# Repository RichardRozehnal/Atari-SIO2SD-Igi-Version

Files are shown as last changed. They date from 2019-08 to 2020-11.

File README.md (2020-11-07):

# Atari SIO2SD Igi Version

SIO2SD je zařízení, které vám umožní nahrávat programy a hry do Atari přes SIO konektor z SD/MMC karty.

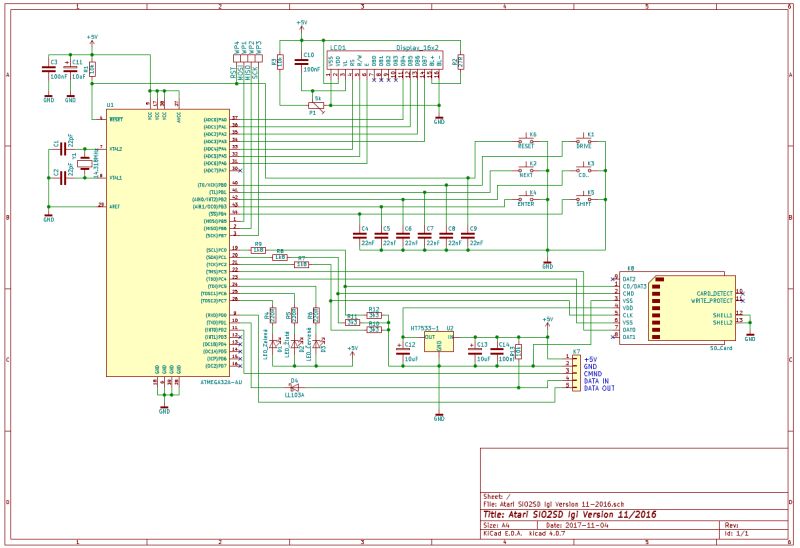
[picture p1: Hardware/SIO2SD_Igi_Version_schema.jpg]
Atari SIO2SD Igi Version schema SIO2SD Igi Version schema


## Seznam součástek:

| Ref | Qnty | Value | Cmp name |
|---|:----:|---|---|
| C1, C2, | 2 | 22pF | C_1206 |
| C9, C8, C7, C6, C5, C4,  | 6 | 22nF | C_1206 |
| C11, C13, C12, | 3 | 10uF | C_Tantal_A/3216 |
| C14, C3, C10, | 3 | 100nF | C_1206 |
| D1, | 1 | LED_Zelená | LED_5mm_Zelená |
| D2, | 1 | LED_Žlutá | LED_5mm_Žlutá |
| D3, | 1 | LED_Červená | LED_5mm_Červená |
| D4, | 1 | LL103A | LL103A |
| K1, | 1 | DRIVE | Mikrospínač_6x6x5mm |
| K2, | 1 | NEXT | Mikrospínač_6x6x5mm |
| K3, | 1 | CD.. | Mikrospínač_6x6x5mm |
| K4, | 1 | ENTER | Mikrospínač_6x6x5mm |
| K5, | 1 | SHIFT | Mikrospínač_6x6x5mm |
| K6, | 1 | RESET | Mikrospínač_6x6x5mm |
| K7, | 1 | KF2510-5_Angled_Pitch2.54mm | KF2510-5_Angled_Pitch2.54mm |
| K8, | 1 | SD_Card | SD_Card |
| LCD1, | 1 | Display_16x2 | Display_16x2 |
| P1, | 1 | 5k | 3362P |
| R1, R3, R13, | 3 | 10k | R_1206 |
| R2, | 1 | 27R | R_1206 |
| R4, R6, R5, | 3 | 220R | R_1206 |
| R9, R8, R7, | 3 | 1k8 | R_1206 |
| R11, R12, R10, | 3 | 3k3 | R_1206 |
| U1, | 1 | ATMEGA32A-AU | ATMEGA32A-AU |
| U2, | 1 | HT7533-1 | HT7533-1 |
| WP1, | 1 | MOSI | Wire_Pad |
| WP2, | 1 | MISO | Wire_Pad |
| WP3, | 1 | SCK | Wire_Pad |
| WP4, | 1 | RST | Wire_Pad |
| Y1, | 1 | 14.318MHz | Krystal_HC49-U_Vertical |

## Fotky hotového výrobku (DPS verze 1):

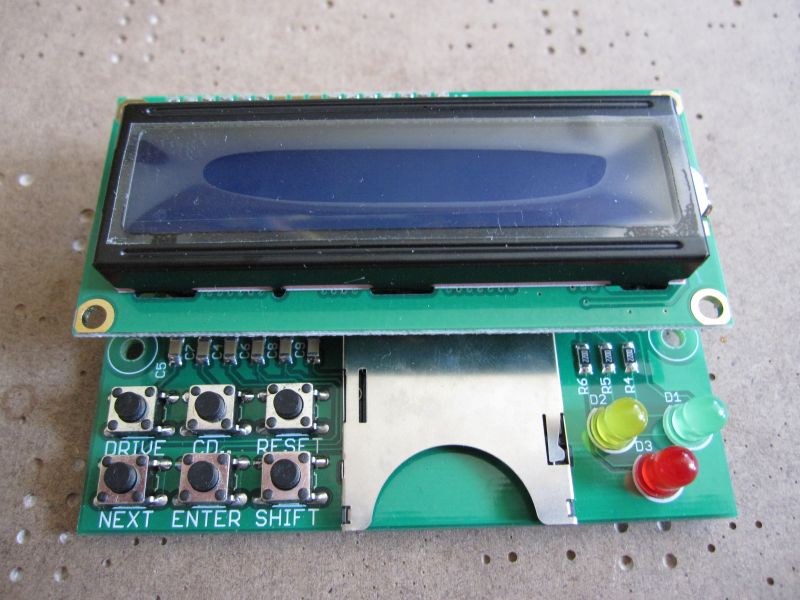
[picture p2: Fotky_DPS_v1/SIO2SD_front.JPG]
Atari SIO2SD front

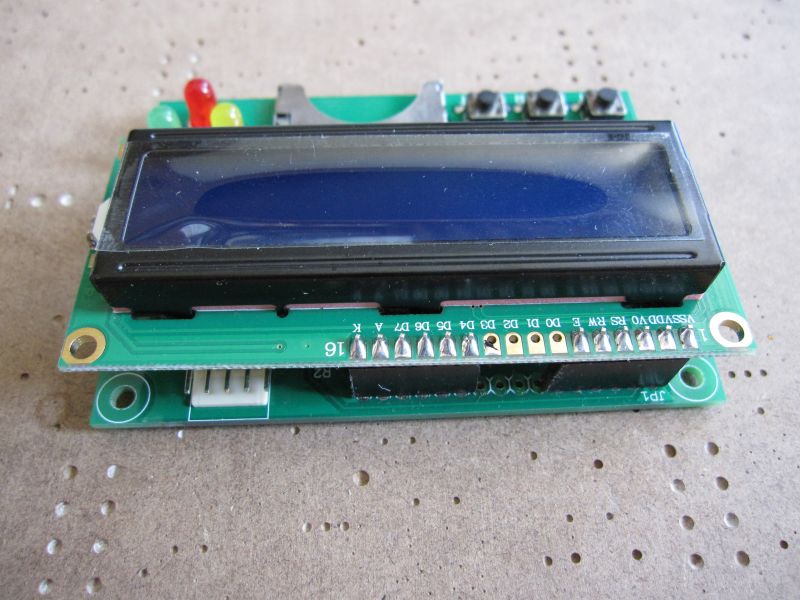
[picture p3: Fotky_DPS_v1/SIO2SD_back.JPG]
Atari SIO2SD back

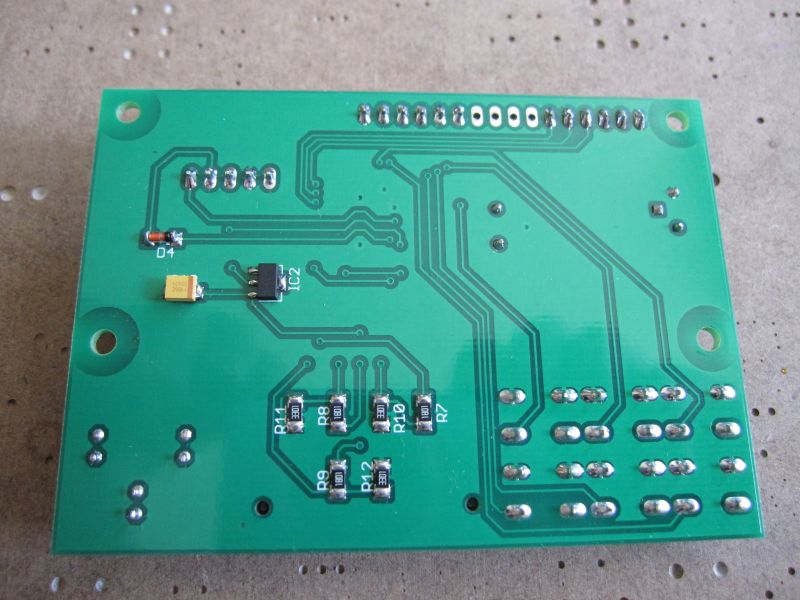
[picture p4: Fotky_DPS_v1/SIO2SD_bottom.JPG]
Atari SIO2SD bottom

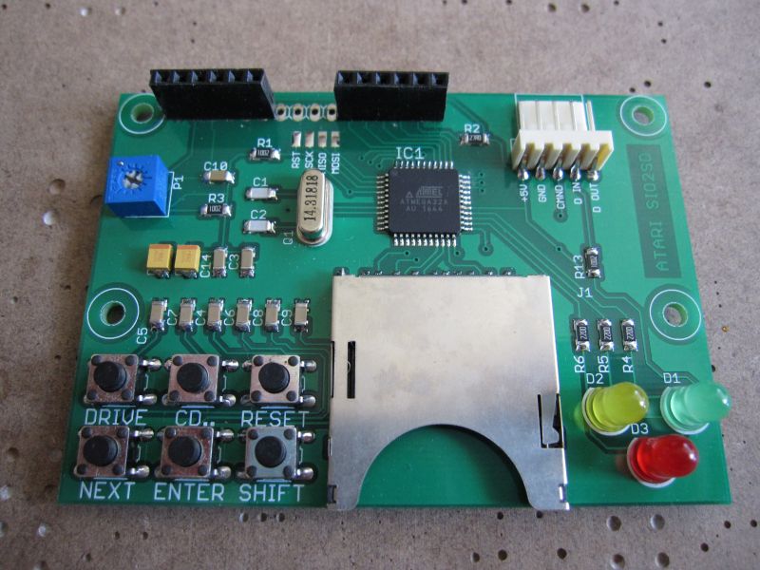
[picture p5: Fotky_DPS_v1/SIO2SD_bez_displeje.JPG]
Atari SIO2SD bez displeje

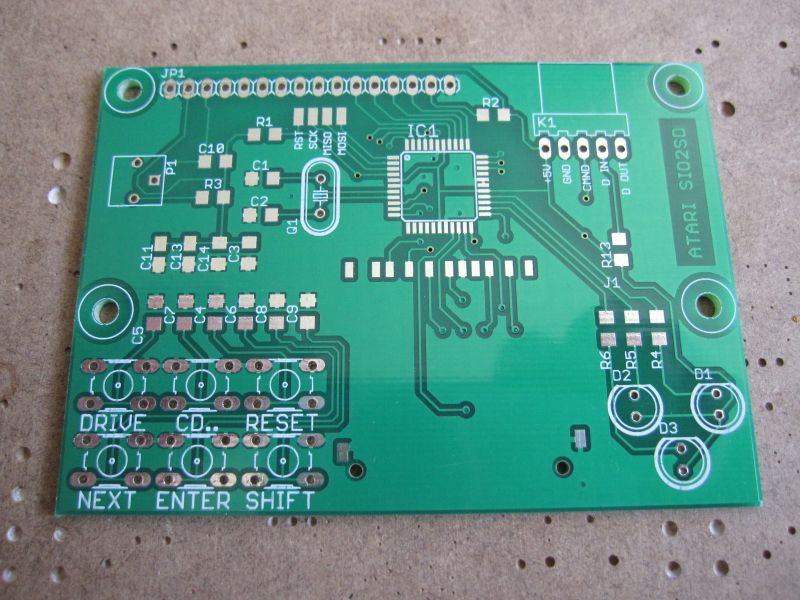
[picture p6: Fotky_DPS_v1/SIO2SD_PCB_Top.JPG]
Atari SIO2SD PCB Top

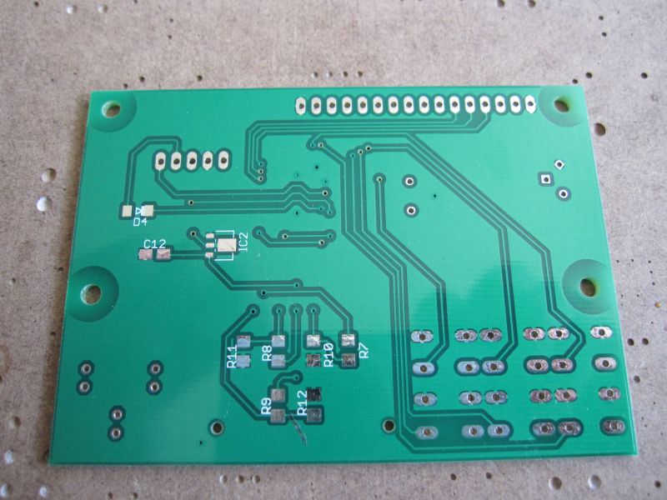
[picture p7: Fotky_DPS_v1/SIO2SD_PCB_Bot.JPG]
Atari SIO2SD PCB Bot


## Původní autoři zařízení jsou:

Device inventor and AVR software developer: Jakub Kruszona-Zawadzki<br>
ATARI software developer and tester: Paweł Nowak (Pajero/MadTeam)<br>
NVC developer: Marcin Sochacki (Montezuma)<br>
Tester (also new SMD PCB designer - still not finished): Jakub Husak<br>

Tato verze má vylepšené a zjednodušené zapojení od [Igiho](http://blog.3b2.sk/igi/post/SIO2SD-3verzia.aspx).
Otestováno na Atari 800XE a vše funguje bez problému.

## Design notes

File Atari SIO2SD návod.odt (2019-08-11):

Atari SIO2SD návod

### Příprava karty

Kartu MMC/SDSC/SDHC (měla by fungovat i SDXC) naformátujte na FAT32. Vytvořte na ni adresář ATARI. Soubor Sio2SD v35.xex z archivu Configurator_35.zip přejmenujte na Sio2SD.xex a přehrejte ho do rootu karty. Do adresáře ATARI přehrejte soubor Sio2SD_CFG_PJ.HLP. V adresáři ATARI můžete vytvářet další adresáře např.: HRY, DEMA, apod. a do těchto již nahrát konkrétní soubory ATR, XEX, COM, XFD. Doporučuje se nahrát maximálně okolo 100 souborů do jednoho adresáře. Protože zařízení SIO2SD nezobrazuje soubory na kartě podle abecedy, ale podle fyzického umístění na kartě, je potřeba (pokud budete chtít) soubory seřadit abecedně pomocí programu DriveSort.

### Příprava kabelu SIO2SD → Atari SIO

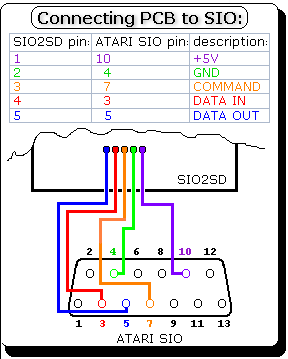
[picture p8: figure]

### Rozložení tlačítek

K1 (DRIVE) | K3 (CD..) | RESET
K2 (NEXT) | K4 (ENTER) | SHIFT

### Ovládání

K1: next atari drive (D1,D2,..)

SHIFT+K1: previous atari drive (D1,D2,..)

K2: next file/folder

SHIFT+K2: previous file/folder

K3: parent directory (cd ..)

SHIFT+K3: swap D1 and D2 (up to version 2.2 - firmware upgrade)

K4: go to folder/map file to current atari drive

SHIFT+K4: turn off current atari drive ("eject disk")

RESET: vyresetuje SIO2SD zařízení

Dvojitým stisknutím tlačítka SHIFT se dostanete do Setup módu. V tomto módu mají tlačítka následující funkce:

K1: next option

SHIFT+K1: previous option

K2: next option setting

SHIFT+K2: previous option setting

K3: back to normal mode

SHIFT+K3: firmware upgrade

### Možnosti nastavení v Setup módu

sio high speed

off

hsindex from 1 to 16 (6 is the default setting)

cfg tool load (when to override D1 to load configuration program)

never

startup+shift - only when SHIFT was pressed during startup (power on)

every startup

D1 is off - When D1 is not assigned

shift pressed - SHIFT always cause D1 override (tested on every SIO 'S' command on D1 - available from version 2.2)

LED mode (meanig of LEDs)

SD read/write - first LED shows SD reads, second LED shows SD writes

SIO read/write - first LED shows SIO reads, second SIO writes

SD act/SIO act - first LED shows any SD activity, second any SIO activity

device id (number of device for SIO2SD.XEX - available from version 2.2)

values from 0 to 3

write protect (write protection in ATR files - available from version 2.2)

never - ATR's are always R/W (write protect flag ignored)

obey ATR flag - obey ATR write protect flag - default

always - ATR's are always R/O

disks to roll (How many disks will be rolled on SHIFT+K3)

values from 2 (swap D1 and D2) to 15 (shift all disks)

key rep delay (keyboard autorepetition delay - in 1/50s.)

values from 0 to 50 (0 - 1s)

key rep step (keyboard autorepetition step - in 1/50s.)

values from 0 to 10 (0 – 0.2s)

### Ovládání v Configurator 3.5

Stiskněte a držte SHIFT na SIO2SD zařízení a zapněte Atari. Nahraje se Configurator ve kterém se zobrazí soubory na kartě, které můžete spouštět.

Spuštění souboru (hry): označte soubor (hru), kterou chcete spustit, stiskněte a držte OPTION na Atari (kvůli vypnutí Atari basicu) a stiskněte na 1-2s klávesu RETURN. OPTION pusťte až se hra začne nahrávat.

Přiřazení souboru k disketovce (D1, D2, atd.): označte požadovaný soubor a stiskněte na Atari klávesnici číslo požadované disketovky.

Odebrání souboru z disketovky (D1, D2, atd.): stiskněte na Atari klávesnici SHIFT + číslo požadované disketovky.

CTRL+T: přepíná mezi L (reálné disketovky), M (mapping), V (virtuální disketovky)

CAPS on/off: zapíná/vypíná skrolování názvů souborů při načítání adresáře

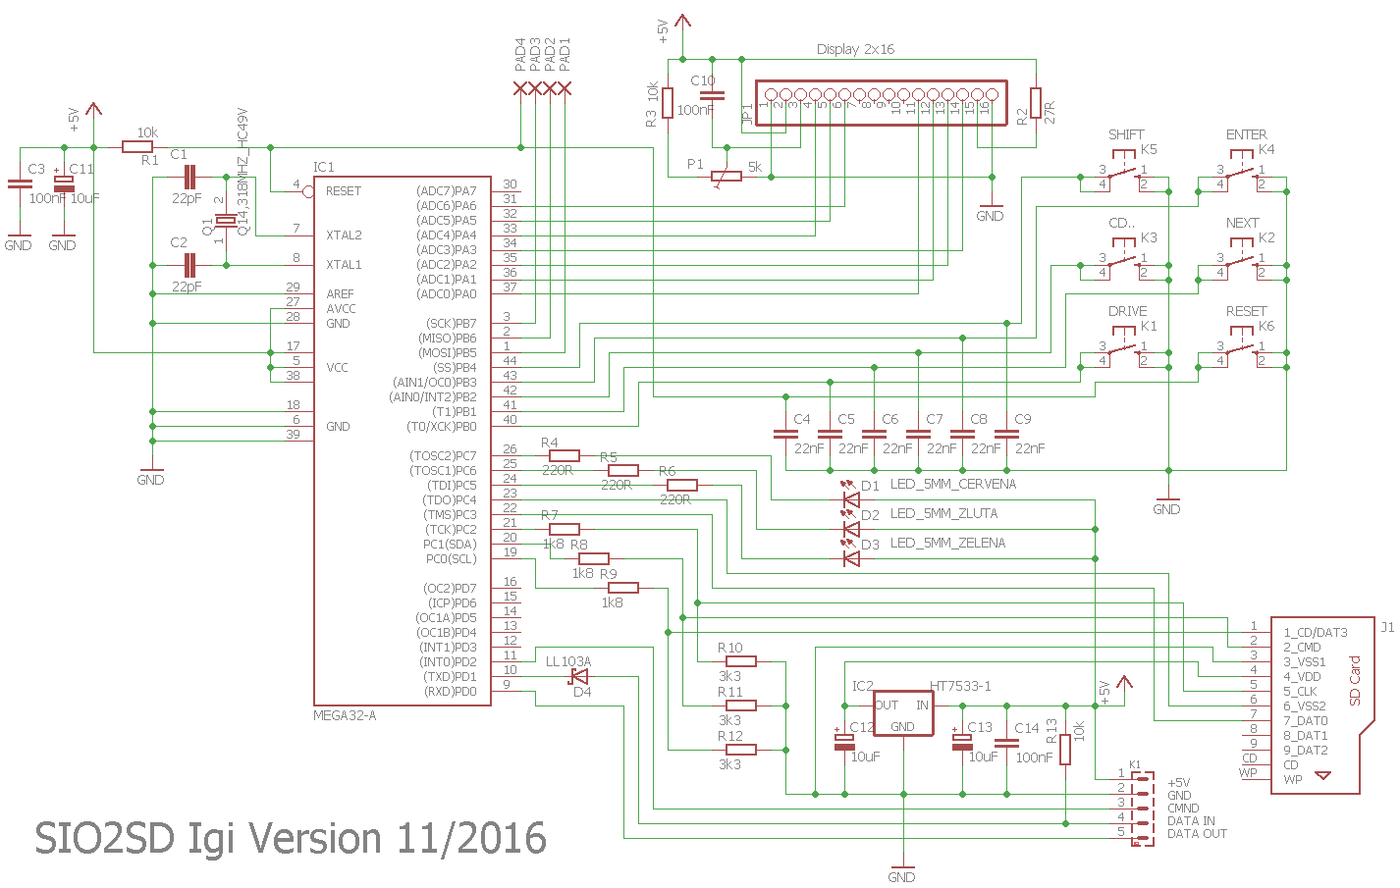
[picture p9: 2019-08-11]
Hardware/1. verze_DPS_v_Eagle/Schema.png

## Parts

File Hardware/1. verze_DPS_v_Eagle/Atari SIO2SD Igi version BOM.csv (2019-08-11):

Qty | Value | Device | Package | Parts | Description
1 |  | 693063010911 | 693063010911 | J1 | WR-CRD SD CARD CONNECTOR PUSH & PULL WITH CARD DETECTION 9PINS=>Code : Con_I-O_COM_CRD_SD_Normal_693063010911
1 |  | PSH02-05W | PSH02-05W | K1 | Konektory se zamkem - vidlice - 5pin
4 |  | SMD2 | SMD1,27-2,54 | PAD1, PAD2, PAD3, PAD4 | SMD PAD
3 | 100nF | C-SMD1206 | 1206 | C3, C10, C14 | Kondenzátory keramické SMD 50 V
3 | 10k | R1206 | R1206 | R1, R3, R13 | Rezistor SMD 1206
3 | 10uF | CTSA | A/3216 | C11, C12, C13 | Kondenzátory tantalové - SMD
3 | 1k8 | R1206 | R1206 | R7, R8, R9 | Rezistor SMD 1206
3 | 220R | R1206 | R1206 | R4, R5, R6 | Rezistor SMD 1206
6 | 22nF | C-SMD1206 | 1206 | C4, C5, C6, C7, C8, C9 | Kondenzátory keramické SMD 50 V
2 | 22pF | C-SMD1206 | 1206 | C1, C2 | Kondenzátory keramické SMD 50 V
1 | 27R | R1206 | R1206 | R2 | Rezistor SMD 1206
3 | 3k3 | R1206 | R1206 | R10, R11, R12 | Rezistor SMD 1206
1 | 5k | 3362P | 3362P | P1 | Odporové trimry 3362P
1 | BAT54S | BAT54S | SOT23 | D4 | Schottky
1 | Display 2x16 | PINHD-1X16 | 1X16 | JP1 | PIN HEADER
1 | HT7533-1 | HT7533-1_SMD | SOT89R | IC2 | VOLTAGE REGULATOR
1 | K1 | 10-XX | B3F-10XX | DRIVE | OMRON SWITCH
1 | K2 | 10-XX | B3F-10XX | NEXT | OMRON SWITCH
1 | K3 | 10-XX | B3F-10XX | CD.. | OMRON SWITCH
1 | K4 | 10-XX | B3F-10XX | ENTER | OMRON SWITCH
1 | K5 | 10-XX | B3F-10XX | SHIFT | OMRON SWITCH
1 | K6 | 10-XX | B3F-10XX | RESET | OMRON SWITCH
1 | LED_5MM_CERVENA | LED_5MM_CERVENA | A5,0 | D1 | LED 5mm
1 | LED_5MM_ZELENA | LED_5MM_ZELENA | A5,0 | D3 | LED 5mm
1 | LED_5MM_ZLUTA | LED_5MM_ZLUTA | A5,0 | D2 | LED 5mm
1 | MEGA32-A | MEGA32-A | TQFP44 | IC1 | MICROCONTROLLER
1 | Q14,318MHZ_HC49V | Q14,318MHZ_HC49V | HC49U-V | Q1 | Krystal s pouzdrem HC-49U

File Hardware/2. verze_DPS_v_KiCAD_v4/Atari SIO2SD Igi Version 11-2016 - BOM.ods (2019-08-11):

Source: | C:/Program Files/KiCad/Projects/Atari SIO2SD Igi Version 11-2016.sch
Date: | 26/11/2017 12:40:37
Tool: | Eeschema 4.0.7
Generator: | KiCad/bin/scripting/plugins/bom_csv_grouped_by_value_with_fp.py
Component Count: | 48
Ref | Qnty | Value | Cmp name
C1, C2, | 2 | 22pF | C_1206
C9, C8, C7, C6, C5, C4, | 6 | 22nF | C_1206
C11, C13, C12, | 3 | 10uF | C_Tantal_A/3216
C14, C3, C10, | 3 | 100nF | C_1206
D1, | 1 | LED_ZelenĂˇ | LED_5mm_ZelenĂˇ
D2, | 1 | LED_Ĺ˝lutĂˇ | LED_5mm_Ĺ˝lutĂˇ
D3, | 1 | LED_ÄŚervenĂˇ | LED_5mm_ÄŚervenĂˇ
D4, | 1 | LL103A | LL103A
K1, | 1 | DRIVE | MikrospĂnaÄŤ_6x6x5mm
K2, | 1 | NEXT | MikrospĂnaÄŤ_6x6x5mm
K3, | 1 | CD.. | MikrospĂnaÄŤ_6x6x5mm
K4, | 1 | ENTER | MikrospĂnaÄŤ_6x6x5mm
K5, | 1 | SHIFT | MikrospĂnaÄŤ_6x6x5mm
K6, | 1 | RESET | MikrospĂnaÄŤ_6x6x5mm
K7, | 1 | KF2510-5_Angled_Pitch2.54mm | KF2510-5_Angled_Pitch2.54mm
K8, | 1 | SD_Card | SD_Card
LCD1, | 1 | Display_16x2 | Display_16x2
P1, | 1 | 5k | 3362P
R1, R3, R13, | 3 | 10k | R_1206
R2, | 1 | 27R | R_1206
R4, R6, R5, | 3 | 220R | R_1206
R9, R8, R7, | 3 | 1k8 | R_1206
R11, R12, R10, | 3 | 3k3 | R_1206
U1, | 1 | ATMEGA32A-AU | ATMEGA32A-AU
U2, | 1 | HT7533-1 | HT7533-1
WP1, | 1 | MOSI | Wire_Pad
WP2, | 1 | MISO | Wire_Pad
WP3, | 1 | SCK | Wire_Pad
WP4, | 1 | RST | Wire_Pad
Y1, | 1 | 14.318MHz | Krystal_HC49-U_Vertical

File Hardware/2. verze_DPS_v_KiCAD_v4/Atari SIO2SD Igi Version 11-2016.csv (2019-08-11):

Source: | C:/Program Files/KiCad/Projects/Atari SIO2SD Igi Version 11-2016.sch
Date: | 26/11/2017 12:40:37
Tool: | Eeschema 4.0.7
Generator: | C:/Program Files/KiCad/bin/scripting/plugins/bom_csv_grouped_by_value_with_fp.py
Component Count: | 48
Ref | Qnty | Value | Cmp name | Footprint | Description | Vendor
C1, C2, | 2 | 22pF | C_1206 | Kondenzátory_SMD:C_1206 | Nepolarizovaný kondenzátor 1206
C9, C8, C7, C6, C5, C4, | 6 | 22nF | C_1206 | Kondenzátory_SMD:C_1206 | Nepolarizovaný kondenzátor 1206
C11, C13, C12, | 3 | 10uF | C_Tantal_A/3216 | Kondenzátory_tantalové_SMD:CP_Tantalum_Case-A_EIA-3216-18_Reflow | Kondenzátor tantalový A/3216
C14, C3, C10, | 3 | 100nF | C_1206 | Kondenzátory_SMD:C_1206 | Nepolarizovaný kondenzátor 1206
D1, | 1 | LED_Zelená | LED_5mm_Zelená | Diody_LED_THT:LED_D5.0mm | LED 5mm Zelená
D2, | 1 | LED_Žlutá | LED_5mm_Žlutá | Diody_LED_THT:LED_D5.0mm | LED 5mm Žlutá
D3, | 1 | LED_Červená | LED_5mm_Červená | Diody_LED_THT:LED_D5.0mm | LED 5mm Červená
D4, | 1 | LL103A | LL103A | Diody_Schottky_SMD:D_MiniMELF | Urrm = 40V, If = 0,2A, Ufm = 0,37V, Ifsm = 15A
K1, | 1 | DRIVE | Mikrospínač_6x6x5mm | Vypínače, přepínače, tlačítka_THT:SW_PUSH_6mm_h5mm | Mikrospínač 6 x 6 x 5 mm, Omron
K2, | 1 | NEXT | Mikrospínač_6x6x5mm | Vypínače, přepínače, tlačítka_THT:SW_PUSH_6mm_h5mm | Mikrospínač 6 x 6 x 5 mm, Omron
K3, | 1 | CD.. | Mikrospínač_6x6x5mm | Vypínače, přepínače, tlačítka_THT:SW_PUSH_6mm_h5mm | Mikrospínač 6 x 6 x 5 mm, Omron
K4, | 1 | ENTER | Mikrospínač_6x6x5mm | Vypínače, přepínače, tlačítka_THT:SW_PUSH_6mm_h5mm | Mikrospínač 6 x 6 x 5 mm, Omron
K5, | 1 | SHIFT | Mikrospínač_6x6x5mm | Vypínače, přepínače, tlačítka_THT:SW_PUSH_6mm_h5mm | Mikrospínač 6 x 6 x 5 mm, Omron
K6, | 1 | RESET | Mikrospínač_6x6x5mm | Vypínače, přepínače, tlačítka_THT:SW_PUSH_6mm_h5mm | Mikrospínač 6 x 6 x 5 mm, Omron
K7, | 1 | KF2510-5_Angled_Pitch2.54mm | KF2510-5_Angled_Pitch2.54mm | Konektory_THT:KF2510-5_Angled_Pitch2.54mm | Konektor KF2510 (PSH02), angled, 5 pinů, 2.54mm
K8, | 1 | SD_Card | SD_Card | Konektory_SMD:SD_Card_Wurth_693061010911 | SD Card Reader
LCD1, | 1 | Display_16x2 | Display_16x2 | Displeje:LCD_16x2 | LCD 16x2
P1, | 1 | 5k | 3362P | Trimry_odporové_THT:3362P | Trimr odporový, 3362P
R1, R3, R13, | 3 | 10k | R_1206 | Rezistory_SMD:R_1206 | Rezistor 1206
R2, | 1 | 27R | R_1206 | Rezistory_SMD:R_1206 | Rezistor 1206
R4, R6, R5, | 3 | 220R | R_1206 | Rezistory_SMD:R_1206 | Rezistor 1206
R9, R8, R7, | 3 | 1k8 | R_1206 | Rezistory_SMD:R_1206 | Rezistor 1206
R11, R12, R10, | 3 | 3k3 | R_1206 | Rezistory_SMD:R_1206 | Rezistor 1206
U1, | 1 | ATMEGA32A-AU | ATMEGA32A-AU | Housings_QFP:TQFP-44_10x10mm_Pitch0.8mm | TQFP44, 32k Flash, 2k SRAM, 1k EEPROM, JTAG
U2, | 1 | HT7533-1 | HT7533-1 | Stabilizátory_SMD:SOT-89R-3 | Stabilizátor napětí 3,3V / 0,1A, max. vstupní napětí 26V, úbytek napětí 0,1V
WP1, | 1 | MOSI | Wire_Pad | Wire_Pads_SMD:Wire_Pad_1.27x2.54mm
WP2, | 1 | MISO | Wire_Pad | Wire_Pads_SMD:Wire_Pad_1.27x2.54mm
WP3, | 1 | SCK | Wire_Pad | Wire_Pads_SMD:Wire_Pad_1.27x2.54mm
WP4, | 1 | RST | Wire_Pad | Wire_Pads_SMD:Wire_Pad_1.27x2.54mm
Y1, | 1 | 14.318MHz | Krystal_HC49-U_Vertical | Krystaly_THT:Crystal_HC49-U_Vertical | Krystal, HC49-U Vertical

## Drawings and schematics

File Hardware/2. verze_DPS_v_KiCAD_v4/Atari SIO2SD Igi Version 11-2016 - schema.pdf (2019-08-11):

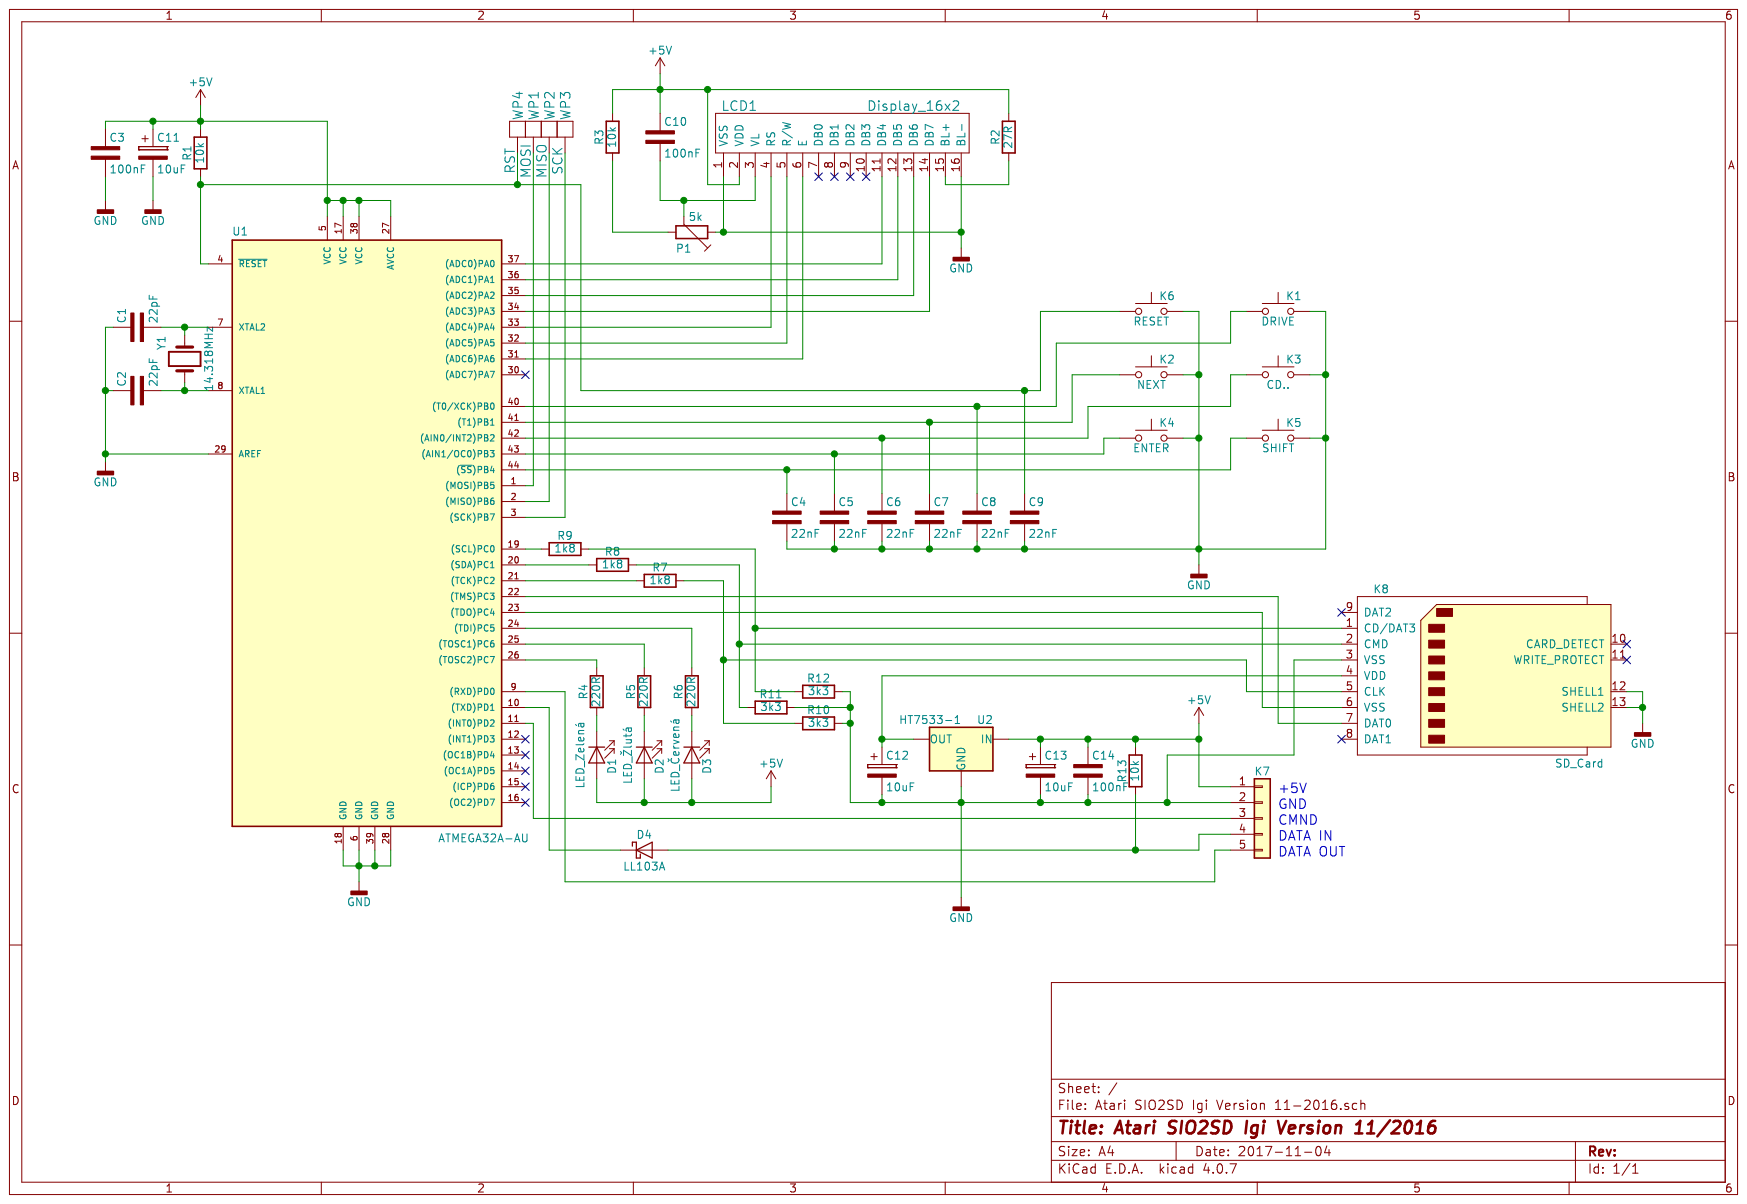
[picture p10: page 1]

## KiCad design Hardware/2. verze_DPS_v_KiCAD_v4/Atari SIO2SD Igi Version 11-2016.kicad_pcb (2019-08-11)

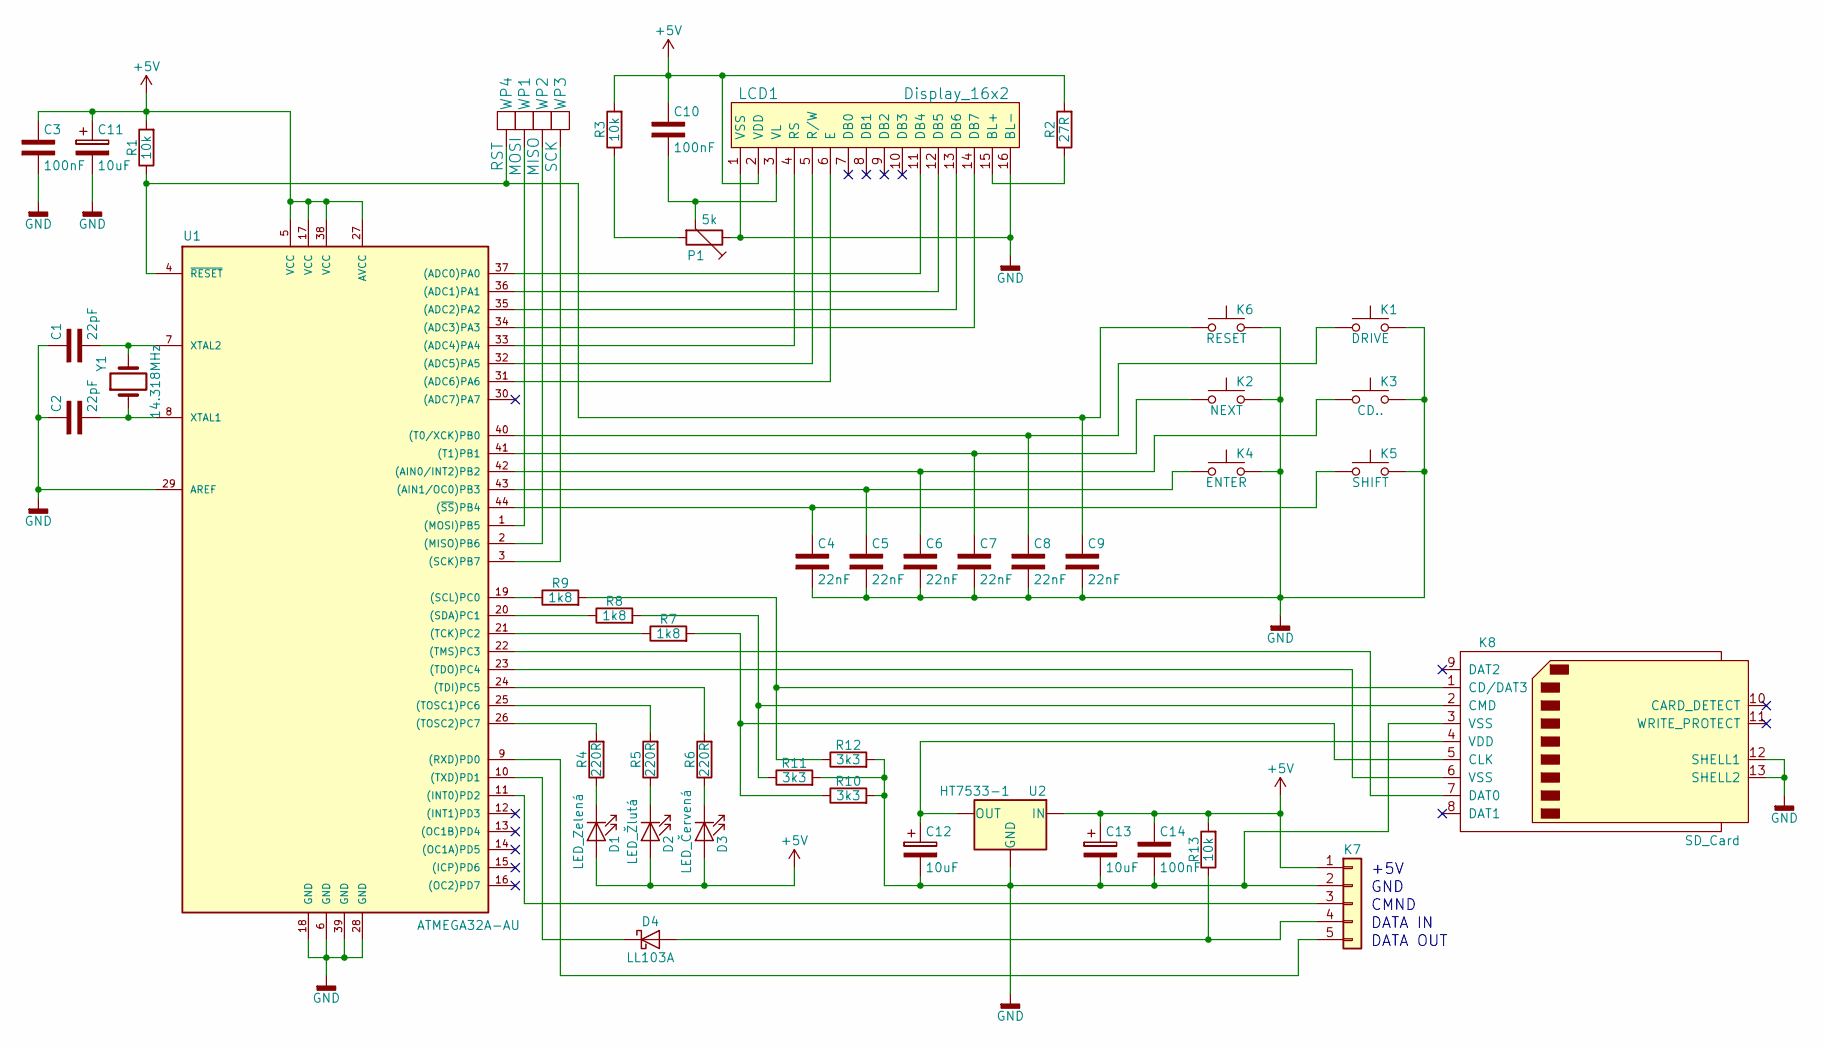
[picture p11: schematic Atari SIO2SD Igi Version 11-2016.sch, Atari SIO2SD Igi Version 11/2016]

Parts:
C1, C2: 22pF; C_1206
C3, C10, C14: 100nF; C_1206
C4, C5, C6, C7, C8, C9: 22nF; C_1206
C11, C12, C13: 10uF; CP_Tantalum_Case-A_EIA-3216-18_Reflow
D1: LED_Zelená; LED_D5.0mm
D2: LED_Žlutá; LED_D5.0mm
D3: LED_Červená; LED_D5.0mm
D4: LL103A; D_MiniMELF
K1: DRIVE; SW_PUSH_6mm_h5mm
K2: NEXT; SW_PUSH_6mm_h5mm
K3: CD..; SW_PUSH_6mm_h5mm
K4: ENTER; SW_PUSH_6mm_h5mm
K5: SHIFT; SW_PUSH_6mm_h5mm
K6: RESET; SW_PUSH_6mm_h5mm
K7: KF2510-5_Angled_Pitch2.54mm
K8: SD_Card; SD_Card_Wurth_693061010911
LCD1: Display_16x2; LCD_16x2
P1: 5k; 3362P
R1, R3, R13: 10k; R_1206
R2: 27R; R_1206
R4, R5, R6: 220R; R_1206
R7, R8, R9: 1k8; R_1206
R10, R11, R12: 3k3; R_1206
U1: ATMEGA32A-AU; TQFP-44_10x10mm_Pitch0.8mm
U2: HT7533-1; SOT-89R-3
WP1: MOSI; Wire_Pad_1.27x2.54mm
WP2: MISO; Wire_Pad_1.27x2.54mm
WP3: SCK; Wire_Pad_1.27x2.54mm
WP4: RST; Wire_Pad_1.27x2.54mm
Y1: 14.318MHz; Crystal_HC49-U_Vertical

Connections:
+5V: C3.1, C10.1, C11.1, C13.1, C14.1, D1.2 (A), D2.2 (A), D3.2 (A), K7.1, LCD1.2 (VDD), R1.2, R2.2, R3.2, R13.2, U1.5 (VCC), U1.17 (VCC), U1.27 (AVCC), U1.38 (VCC), U2.2 (IN)
GND: C1.1, C2.1, C3.2, C4.2, C5.2, C6.2, C7.2, C8.2, C9.2, C11.2, C12.2, C13.2, C14.2, K1.2, K2.2, K3.2, K4.2, K5.2, K6.2, K7.2, K8.3 (VSS), K8.12 (SHELL1), K8.13 (SHELL2), LCD1.1 (VSS), LCD1.16 (BL-), P1.3, R10.2, R11.2, R12.2, U1.6 (GND), U1.18 (GND), U1.28 (GND), U1.29 (AREF), U1.39 (GND), U2.1 (GND)
unnamed: C1.2, U1.7 (XTAL2), Y1.2
unnamed: C2.2, U1.8 (XTAL1), Y1.1
unnamed: C4.1, K5.1, U1.44 ((~SS~)PB4)
unnamed: C5.1, K4.1, U1.43 ((AIN1/OC0)PB3)
unnamed: C6.1, K3.1, U1.42 ((AIN0/INT2)PB2)
unnamed: C7.1, K2.1, U1.41 ((T1)PB1)
unnamed: C8.1, K1.1, U1.40 ((T0/XCK)PB0)
unnamed 9: C9.1, K6.1, R1.1, U1.4 (~RESET), WP4.1; also elsewhere on the board
unnamed: C10.2, LCD1.3 (VL), P1.2
unnamed: C12.1, K8.4 (VDD), U2.3 (OUT)
unnamed: D1.1 (K), R4.1
unnamed: D2.1 (K), R5.1
unnamed: D3.1 (K), R6.1
unnamed: D4.1 (K), U1.10 ((TXD)PD1)
unnamed: D4.2 (A), K7.4, R13.1
unnamed: K7.3, U1.11 ((INT0)PD2)
unnamed: K7.5, U1.9 ((RXD)PD0)
unnamed: K8.1 (CD/DAT3), R9.2, R12.1
unnamed: K8.2 (CMD), R8.2, R11.1
unnamed: K8.5 (CLK), R7.2, R10.1
unnamed: K8.6 (VSS), U1.23 ((TDO)PC4)
unnamed: K8.7 (DAT0), U1.22 ((TMS)PC3)
unnamed: LCD1.4 (RS), U1.33 ((ADC4)PA4)
unnamed: LCD1.5 (R/W), U1.32 ((ADC5)PA5)
unnamed: LCD1.6 (E), U1.31 ((ADC6)PA6)
unnamed: LCD1.11 (DB4), U1.37 ((ADC0)PA0)
unnamed: LCD1.12 (DB5), U1.36 ((ADC1)PA1)
unnamed: LCD1.13 (DB6), U1.35 ((ADC2)PA2)
unnamed: LCD1.14 (DB7), U1.34 ((ADC3)PA3)
unnamed: LCD1.15 (BL+), R2.1
unnamed: P1.1, R3.1
unnamed: R4.2, U1.26 ((TOSC2)PC7)
unnamed: R5.2, U1.25 ((TOSC1)PC6)
unnamed: R6.2, U1.24 ((TDI)PC5)
unnamed: R7.1, U1.21 ((TCK)PC2)
unnamed: R8.1, U1.20 ((SDA)PC1)
unnamed: R9.1, U1.19 ((SCL)PC0)
unnamed 47: U1.1 ((MOSI)PB5), WP1.1; also elsewhere on the board
unnamed 48: U1.2 ((MISO)PB6), WP2.1; also elsewhere on the board
unnamed 49: U1.3 ((SCK)PB7), WP3.1; also elsewhere on the board

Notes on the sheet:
+5V
GND
CMND
DATA IN
DATA OUT

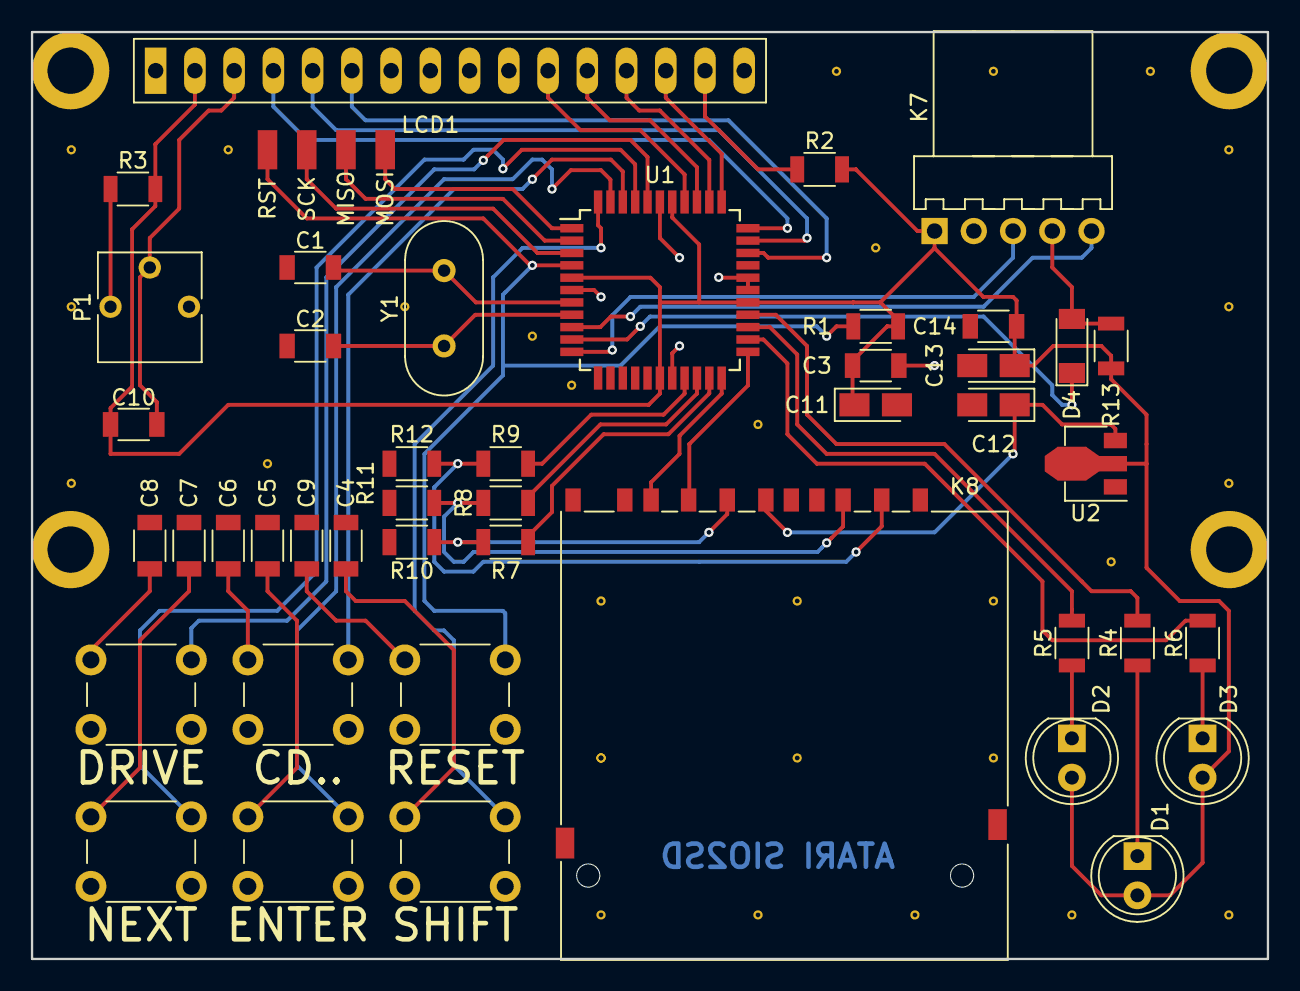
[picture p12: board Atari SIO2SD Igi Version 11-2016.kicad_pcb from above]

Board: 2 copper layers, 80.0 x 60.0 mm, 48 parts (0 on the bottom side), 42 nets.

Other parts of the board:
MISO: Wire_Pad_1.27x2.54mm
MOSI: Wire_Pad_1.27x2.54mm
RST: Wire_Pad_1.27x2.54mm
SCK: Wire_Pad_1.27x2.54mm

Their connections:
unnamed 9: RST.1; also elsewhere on the board
unnamed 47: MOSI.1; also elsewhere on the board
unnamed 48: MISO.1; also elsewhere on the board
unnamed 49: SCK.1; also elsewhere on the board

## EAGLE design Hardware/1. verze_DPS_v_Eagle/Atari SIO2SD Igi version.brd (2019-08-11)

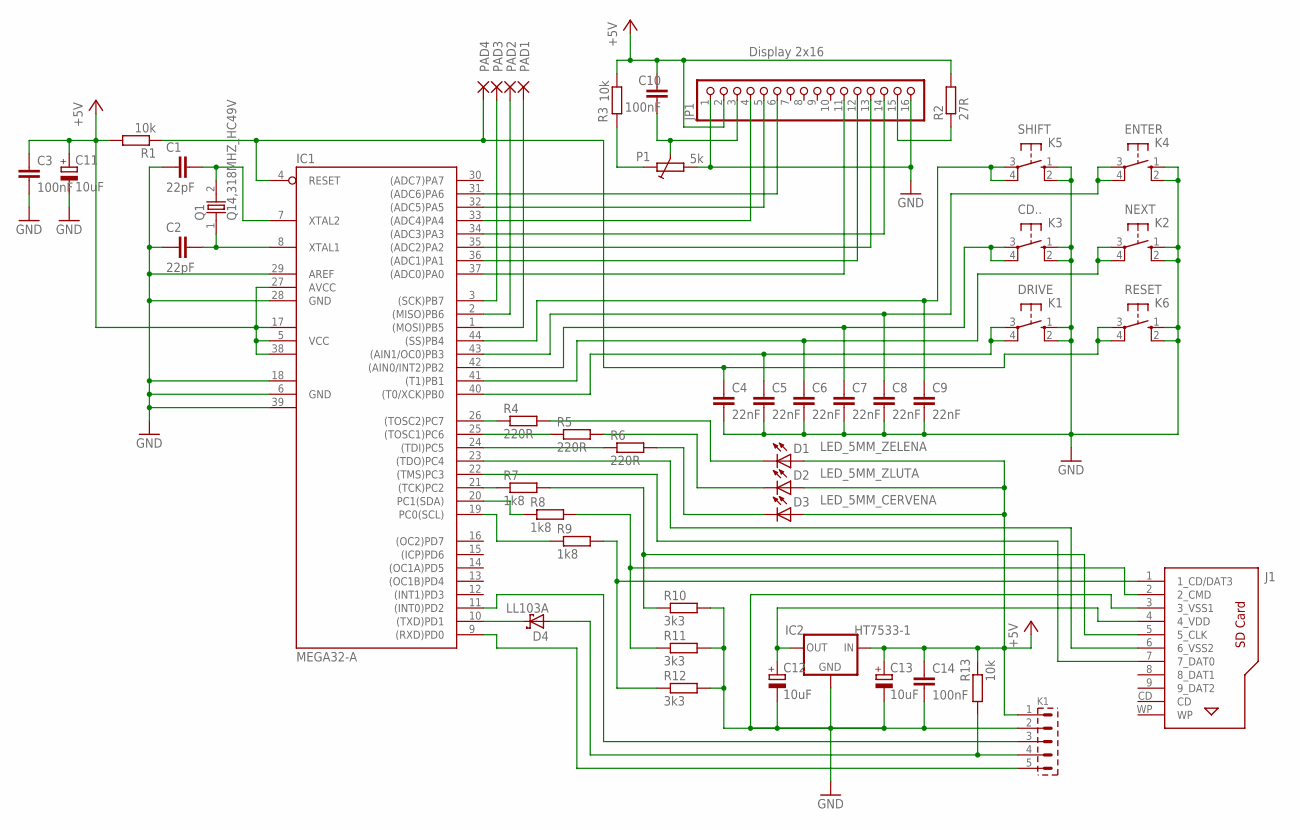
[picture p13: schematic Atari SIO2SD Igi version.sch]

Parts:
C1, C2: 22pF; 1206
C3, C10, C14: 100nF; 1206
C4, C5, C6, C7, C8, C9: 22nF; 1206
C11, C12, C13: 10uF; A/3216
CD..: K3; B3F-10XX
D1: LED_5MM_ZELENA; A5,0
D2: LED_5MM_ZLUTA; A5,0
D3: LED_5MM_CERVENA; A5,0
D4: LL103A; MINIMELF
DRIVE: K1; B3F-10XX
ENTER: K4; B3F-10XX
IC1: MEGA32-A; TQFP44
IC2: HT7533-1; SOT89R
J1: 693061010911
JP1: Display 2x16; 1X16
K1: PSH02-05W
NEXT: K2; B3F-10XX
P1: 5k; 3362P
PAD1, PAD2, PAD3, PAD4: SMD2; SMD1,27-2,54
Q1: Q14,318MHZ_HC49V; HC49U-V
R1, R3, R13: 10k; R1206
R2: 27R; R1206
R4, R5, R6: 220R; R1206
R7, R8, R9: 1k8; R1206
R10, R11, R12: 3k3; R1206
RESET: K6; B3F-10XX
SHIFT: K5; B3F-10XX

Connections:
+5V: C3.1, C10.1, C11.+, C13.+, C14.1, D1.A, D2.A, D3.A, IC1.5 (VCC), IC1.17 (VCC1), IC1.27 (AVCC), IC1.38 (VCC2), IC2.2 (IN), IC2.4 (IN), JP1.2, K1.1, R1.2, R2.2, R3.1, R13.2
GND: C1.1, C2.1, C3.2, C4.2, C5.2, C6.2, C7.2, C8.2, C9.2, C11.-, C12.-, C13.-, C14.2, CD...1 (S), CD...2 (S1), DRIVE.1 (S), DRIVE.2 (S1), ENTER.1 (S), ENTER.2 (S1), IC1.6 (GND), IC1.18 (GND1), IC1.28 (GND), IC1.29 (AREF), IC1.39 (GND2), IC2.1 (GND), J1.3 (3_VSS1), JP1.1, JP1.16, K1.2, NEXT.1 (S), NEXT.2 (S1), P1.A (1), R10.2, R11.2, R12.2, RESET.1 (S), RESET.2 (S1), SHIFT.1 (S), SHIFT.2 (S1)
unnamed: C1.2, IC1.7 (XTAL2), Q1.2
unnamed: C2.2, IC1.8 (XTAL1), Q1.1
unnamed: C10.2, JP1.3, P1.S (3)
unnamed: IC1.26 ((TOSC2)PC7), R4.1
unnamed: P1.E (2), R3.2
unnamed: C7.1, CD...3, CD...4 (P1), IC1.42 ((AIN0/INT2)PB2)
unnamed: IC1.31 ((ADC6)PA6), JP1.6
unnamed: JP1.15, R2.1
unnamed: IC1.32 ((ADC5)PA5), JP1.5
unnamed: IC1.33 ((ADC4)PA4), JP1.4
unnamed: IC1.34 ((ADC3)PA3), JP1.14
unnamed: IC1.35 ((ADC2)PA2), JP1.13
unnamed: IC1.36 ((ADC1)PA1), JP1.12
unnamed: IC1.37 ((ADC0)PA0), JP1.11
unnamed: C9.1, IC1.44 ((SS)PB4), SHIFT.3, SHIFT.4 (P1)
unnamed: C8.1, ENTER.3, ENTER.4 (P1), IC1.43 ((AIN1/OC0)PB3)
unnamed: IC1.25 ((TOSC1)PC6), R5.1
unnamed: C6.1, IC1.41 ((T1)PB1), NEXT.3, NEXT.4 (P1)
unnamed: C5.1, DRIVE.3, DRIVE.4 (P1), IC1.40 ((T0/XCK)PB0)
unnamed: C4.1, IC1.4 (RESET), PAD4.1, R1.1, RESET.3, RESET.4 (P1)
unnamed: IC1.24 ((TDI)PC5), R6.1
unnamed: D1.K (C), R4.2
unnamed: D2.K (C), R5.2
unnamed: D3.K (C), R6.2
unnamed: IC1.1 ((MOSI)PB5), PAD1.1
unnamed: IC1.23 ((TDO)PC4), J1.6 (6_VSS2)
unnamed: IC1.22 ((TMS)PC3), J1.7 (7_DAT0)
unnamed: IC1.21 ((TCK)PC2), R7.1
unnamed: IC1.20 (PC1(SDA)), R8.1
unnamed: IC1.19 (PC0(SCL)), R9.1
unnamed: J1.5 (5_CLK), R7.2, R10.1
unnamed: J1.2 (2_CMD), R8.2, R11.1
unnamed: J1.1 (1_CD/DAT3), R9.2, R12.1
unnamed: C12.+, IC2.3 (OUT), J1.4 (4_VDD)
unnamed: D4.C, IC1.10 ((TXD)PD1)
unnamed: D4.A, K1.4, R13.1
unnamed: IC1.11 ((INT0)PD2), K1.3
unnamed: IC1.9 ((RXD)PD0), K1.5
unnamed: IC1.2 ((MISO)PB6), PAD2.1
unnamed: IC1.3 ((SCK)PB7), PAD3.1

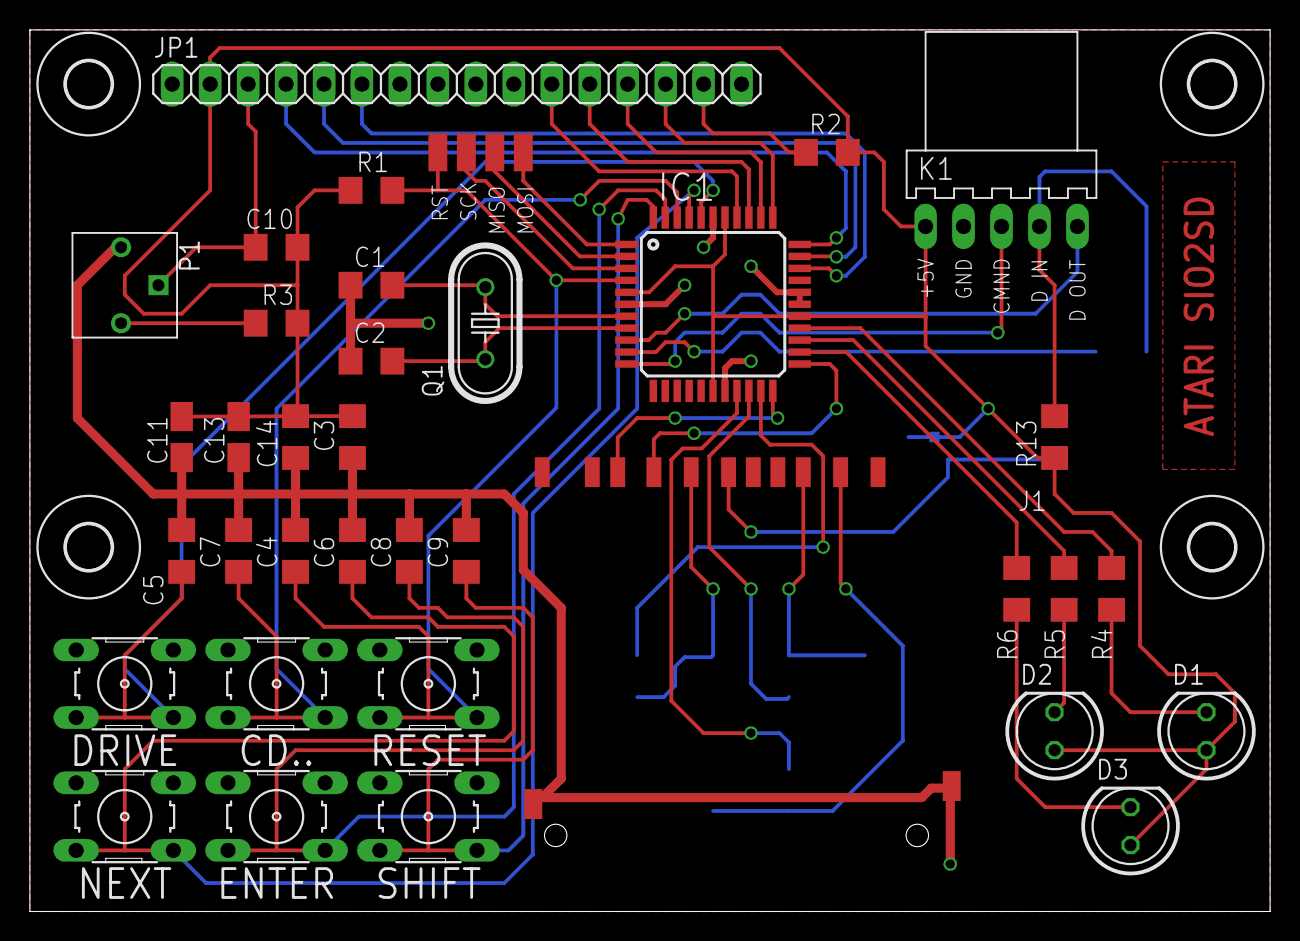
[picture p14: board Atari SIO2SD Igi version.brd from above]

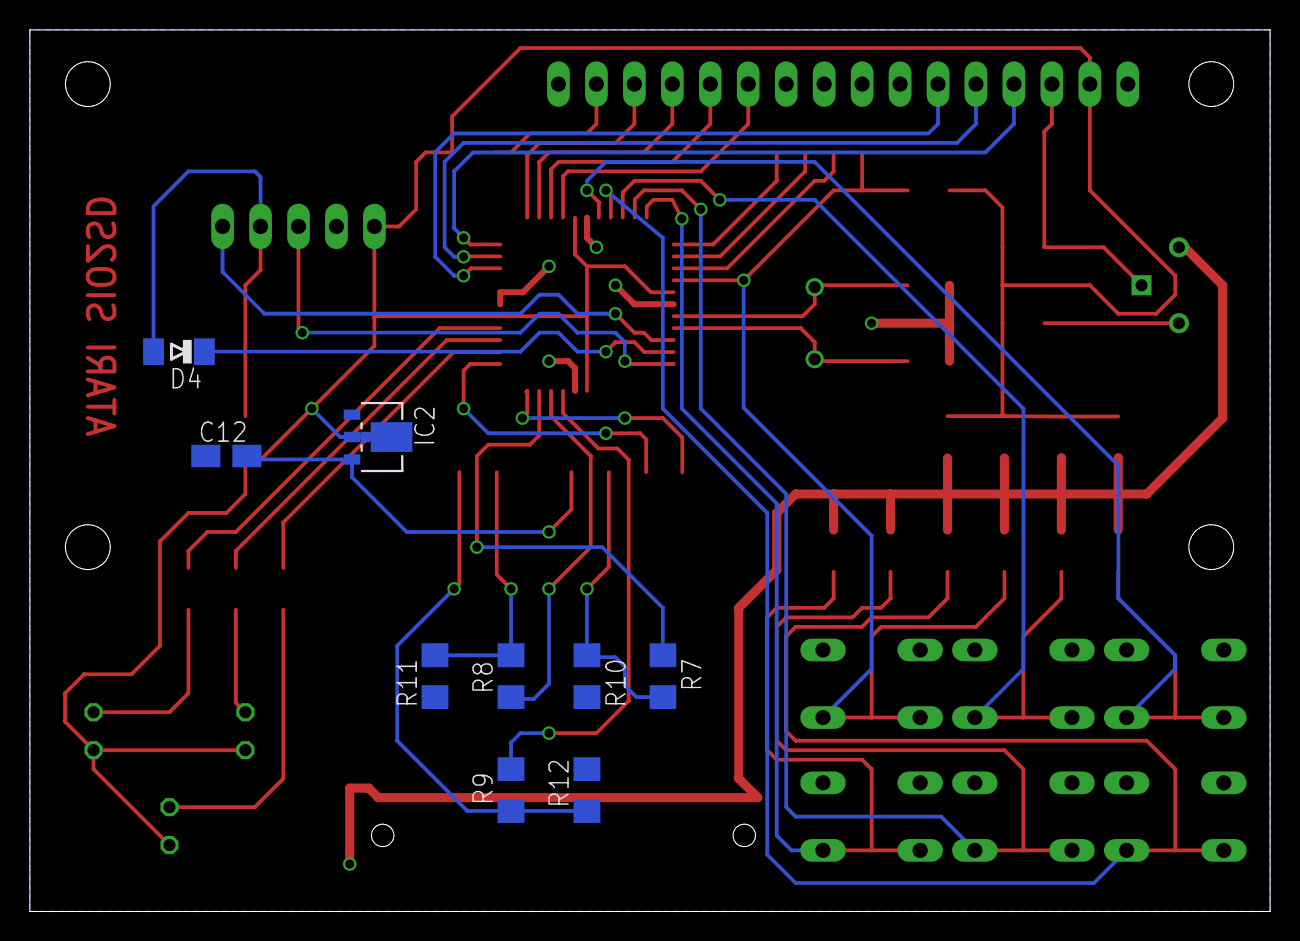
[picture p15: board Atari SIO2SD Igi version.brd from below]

Board: 2 copper layers, 83.0 x 59.0 mm, 52 parts (9 on the bottom side), 42 nets.

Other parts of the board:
U$1, U$2, U$3, U$4: 3,0

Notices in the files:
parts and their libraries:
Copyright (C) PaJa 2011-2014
